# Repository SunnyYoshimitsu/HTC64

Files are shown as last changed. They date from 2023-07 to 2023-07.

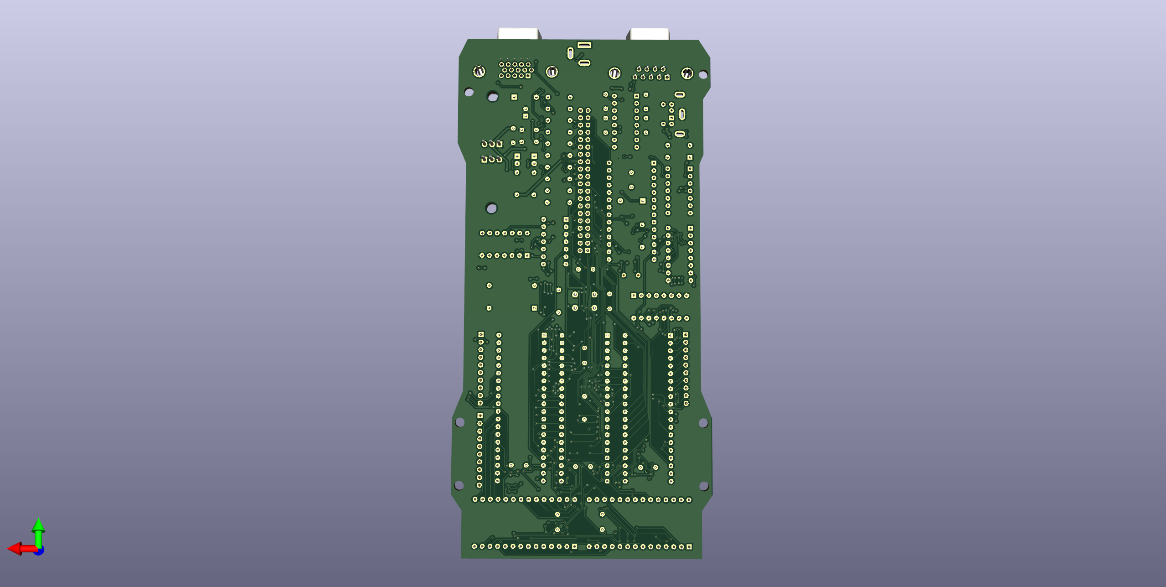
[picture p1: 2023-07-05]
Picture Y!6502/Back Visual.png

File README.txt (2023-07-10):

# Y!6502
Think Ben Eater's 6502 but modified....a modified BE6592...the Y!6502....

I modified this computer to have 2 VIA chips instead of just one since I think having more GPIO will allow it to be used as a more conventional microcontroller. Also I changed the memory layout and add a larger RAM. So the memory layout ended up being inverted to Ben's, 32k of RAM and 16k of ROM. There's an expansion slot in the middle designed to take a stock Ben Eater's GPU with its !DMA config or any other peripherals you want. The expansion slot is mapped to A000 - BFFF. 

Note there's a VGA output and associtated resistors, however there are no GPU to drive it. This is for the expansion slot. I am planning a "modified" BE6502 GPU that uses a dual port RAM so that the CPU can run at 100% capacity. Now this computer is basically everything that the BE6502 is except for the GPU but ofcourse you don't have to populate everything. 

I'm porting Wozmon to this modifed BE6502 since the UART is in a different place and it does support a keyboard. I will update this repo as soon as I'm done with it. 

If you have any question or ideas please don't hesitate to hit me up! I am an active user in the r/beneater subreddit. 
Profile: https://www.reddit.com/user/YoshimitsuSunny

Memory Layout: 
	Note: each section is 8k in size
0000 - 1FFF: RAM
2000 - 3FFF: RAM 
4000 - 5FFF: RAM 
6000 - 7FFF: RAM
8000 - 9FFF: DDRAM 
A000 - BFFF: Peripheral
A200 - UART
A400 - A40F: I/O Timer 1
  Reg A: GPIO
  Reg B: P/S 2
A800 - A80F: I/O Timer 2
  Reg A: GPIO
  Reg B: GPIO
C000 - DFFF: ROM (lower address) 
E000 - FFFF: ROM (higher address)

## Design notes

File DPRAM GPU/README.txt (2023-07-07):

The PCB version is incomplete!!!!!! Don't use it. I'll fix it at a later date. However, the schematic should be correct. Have fun!

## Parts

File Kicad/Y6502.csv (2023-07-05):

# | Reference | Qty | Value | Footprint | DNP
1 | A6522 | 1 | I/O Timer 1 | Package_DIP:DIP-40_W15.24mm_Socket
2 | B6522 | 1 | I/O Timer 2 | Package_DIP:DIP-40_W15.24mm_Socket
3 | C1 | 1 | .1uF | Capacitor_THT:C_Disc_D6.0mm_W2.5mm_P5.00mm
4 | C2, C4, C5, C6, C7, C8, C9, C10, C12, C13, C14, C15, C16, C17 | 14 | 1uF | Capacitor_THT:C_Disc_D6.0mm_W2.5mm_P5.00mm
5 | C3 | 1 | 47uF | Capacitor_THT:CP_Radial_D5.0mm_P2.50mm
6 | C11 | 1 | 20uF | Capacitor_THT:C_Disc_D6.0mm_W2.5mm_P5.00mm
7 | D1, D5 | 2 | 1N4007 | Diode_THT:D_A-405_P7.62mm_Horizontal
8 | D2, D3 | 2 | LED | LED_THT:LED_D3.0mm
9 | D4 | 1 | 1N914 | Diode_THT:D_DO-35_SOD27_P7.62mm_Horizontal
10 | J1 | 1 | Barrel_Jack_Power | Connector_BarrelJack:BarrelJack_GCT_DCJ200-10-A_Horizontal
11 | J2 | 1 | P/S 2 Breakout | Custom_Footprints:Connector_Mini-DIN_Female_6Pin_2rows
12 | J3 | 1 | R232 Plug | Connector_Dsub:DSUB-9_Female_Horizontal_P2.77x2.84mm_EdgePinOffset9.90mm_Housed_MountingHolesOffset11.32mm
13 | R1, R2 | 2 | 1k | Resistor_THT:R_Axial_DIN0207_L6.3mm_D2.5mm_P7.62mm_Horizontal
14 | R3, R4 | 2 | 22K | Resistor_THT:R_Axial_DIN0207_L6.3mm_D2.5mm_P7.62mm_Horizontal
15 | R5 | 1 | 33k | Resistor_THT:R_Axial_DIN0207_L6.3mm_D2.5mm_P7.62mm_Horizontal
16 | R6, R7, R8 | 3 | 1.5k | Resistor_THT:R_Axial_DIN0207_L6.3mm_D2.5mm_P7.62mm_Horizontal
17 | R9, R10, R11 | 3 | 680 | Resistor_THT:R_Axial_DIN0207_L6.3mm_D2.5mm_P7.62mm_Horizontal
18 | R12, R13 | 2 | 220 | Resistor_THT:R_Axial_DIN0207_L6.3mm_D2.5mm_P7.62mm_Horizontal
19 | R14, R15 | 2 | 100 | Resistor_THT:R_Axial_DIN0207_L6.3mm_D2.5mm_P7.62mm_Horizontal
20 | ROM1 | 1 | 27C128 ROM | Package_DIP:DIP-28_W15.24mm_Socket
21 | Rw9 | 1 | 1M | Resistor_THT:R_Axial_DIN0207_L6.3mm_D2.5mm_P7.62mm_Horizontal
22 | SW1 | 1 | SW_Push | Button_Switch_THT:SW_PUSH_6mm
23 | U1, U7, U8 | 3 | ~ | Connector_PinSocket_2.54mm:PinSocket_1x10_P2.54mm_Vertical
24 | U2, U4 | 2 | LM1117DT-5.0 | Package_TO_SOT_THT:TO-220-3_Horizontal_TabDown
25 | U3 | 1 | 6502 CPU | Package_DIP:DIP-40_W15.24mm_Socket
26 | U5 | 1 | 74LS00 | Package_DIP:DIP-14_W7.62mm
27 | U6 | 1 | 74LS32 | Package_DIP:DIP-14_W7.62mm
28 | U12 | 1 | 74LS14 | Package_DIP:DIP-14_W7.62mm
29 | U13, U14 | 2 | 74LS595 | Package_DIP:DIP-16_W7.62mm
30 | U15 | 1 | 6551 | Package_DIP:DIP-28_W15.24mm_Socket
31 | U16 | 1 | MAX232 | Package_DIP:DIP-16_W7.62mm
32 | URAM1 | 1 | 62256 RAM | Package_DIP:DIP-28_W15.24mm_Socket
33 | VGA1 | 1 | VGA Output | Connector_Dsub:DSUB-15-HD_Female_Horizontal_P2.29x1.98mm_EdgePinOffset8.35mm_Housed_MountingHolesOffset10.89mm
34 | X2 | 1 | 1 MHz Osc | Oscillator:Oscillator_DIP-14
35 | Y1 | 1 | 1.8432 Mhz | Crystal:Crystal_HC18-U_Vertical
36 | ~1 | 1 | ~ | Connector_PinSocket_2.54mm:PinSocket_2x20_P2.54mm_Vertical

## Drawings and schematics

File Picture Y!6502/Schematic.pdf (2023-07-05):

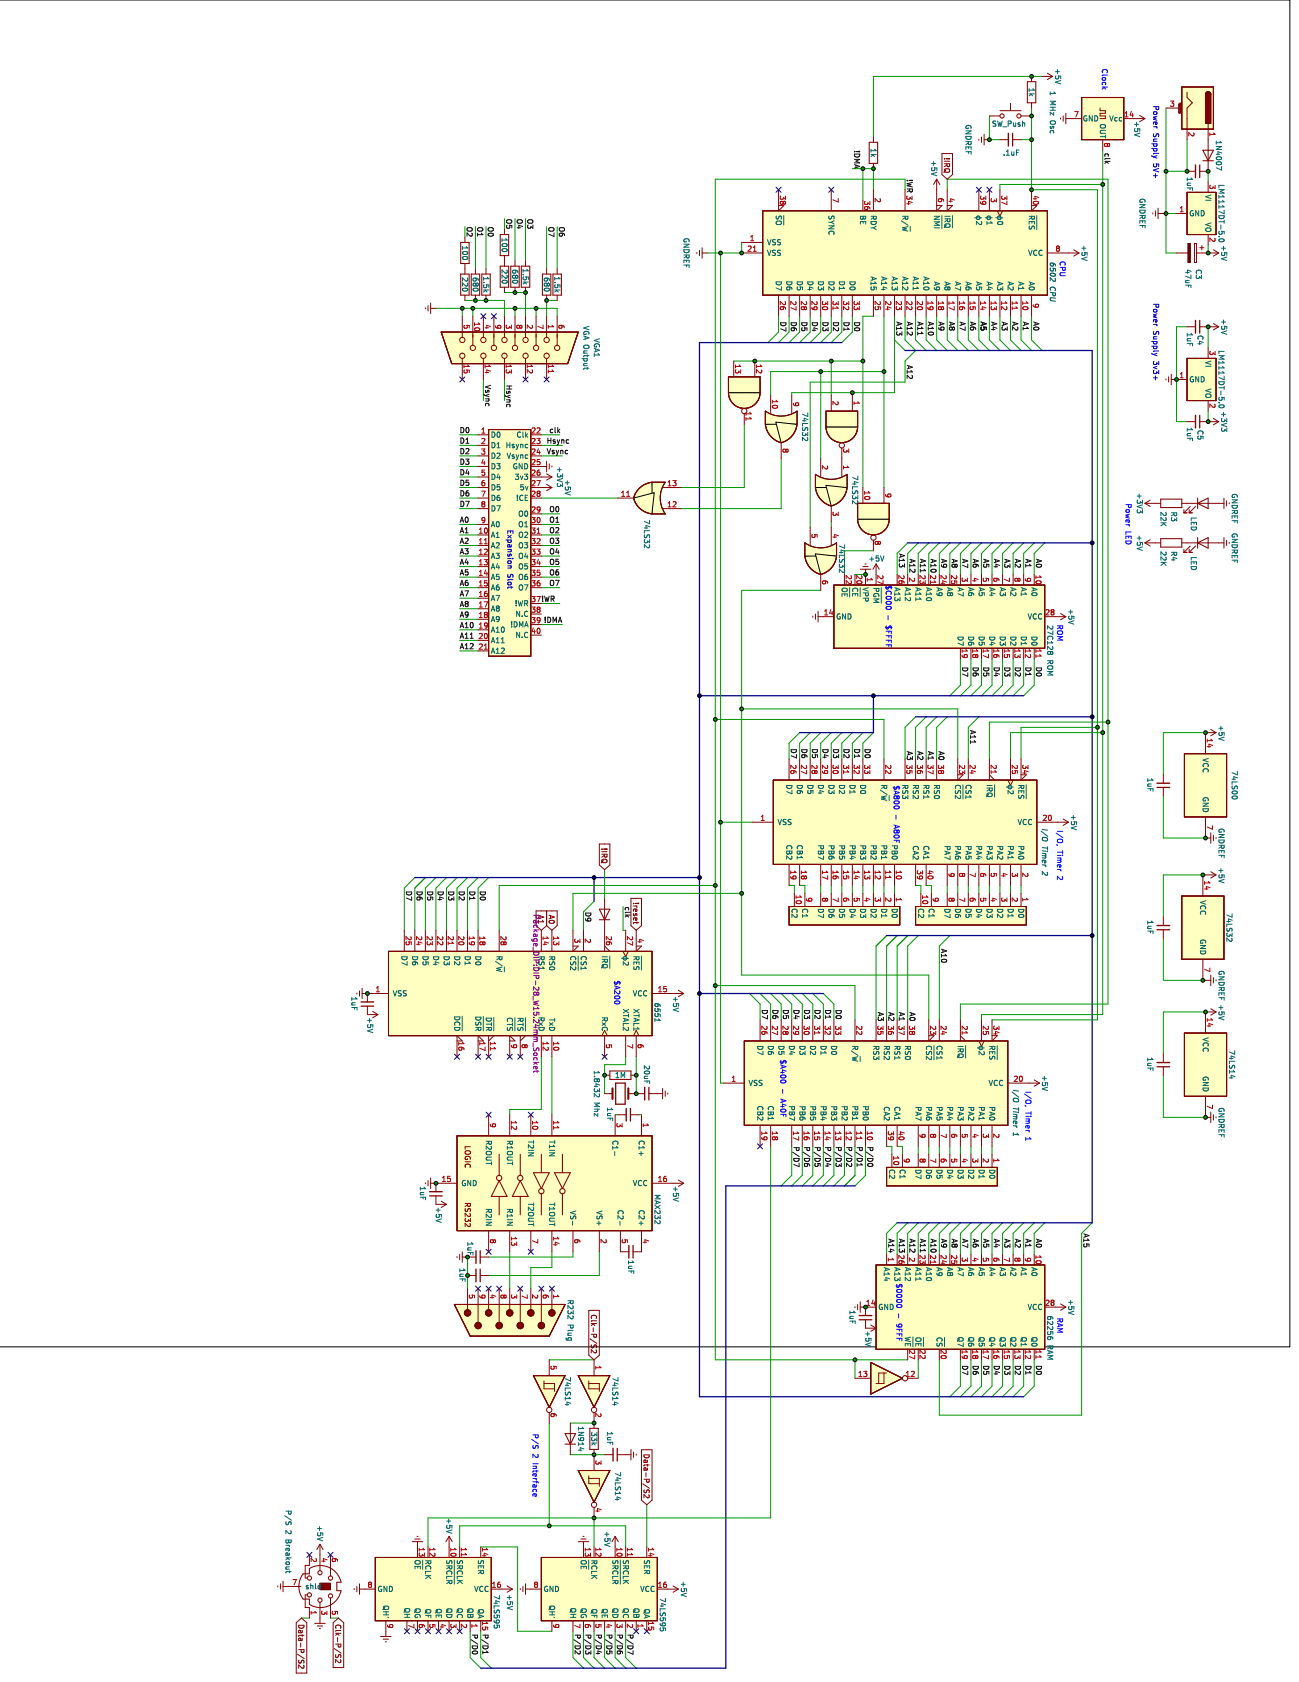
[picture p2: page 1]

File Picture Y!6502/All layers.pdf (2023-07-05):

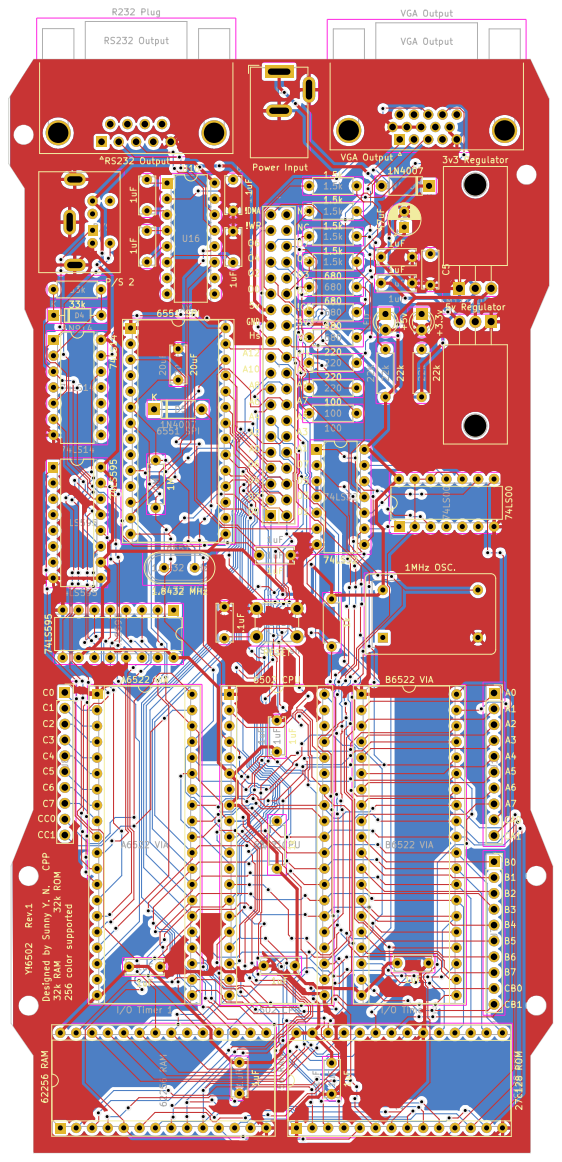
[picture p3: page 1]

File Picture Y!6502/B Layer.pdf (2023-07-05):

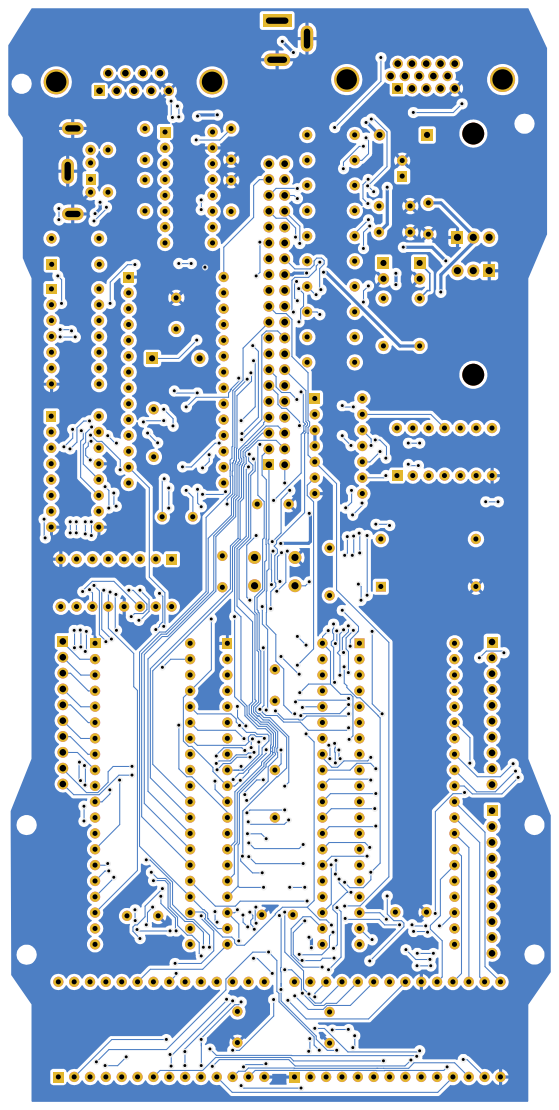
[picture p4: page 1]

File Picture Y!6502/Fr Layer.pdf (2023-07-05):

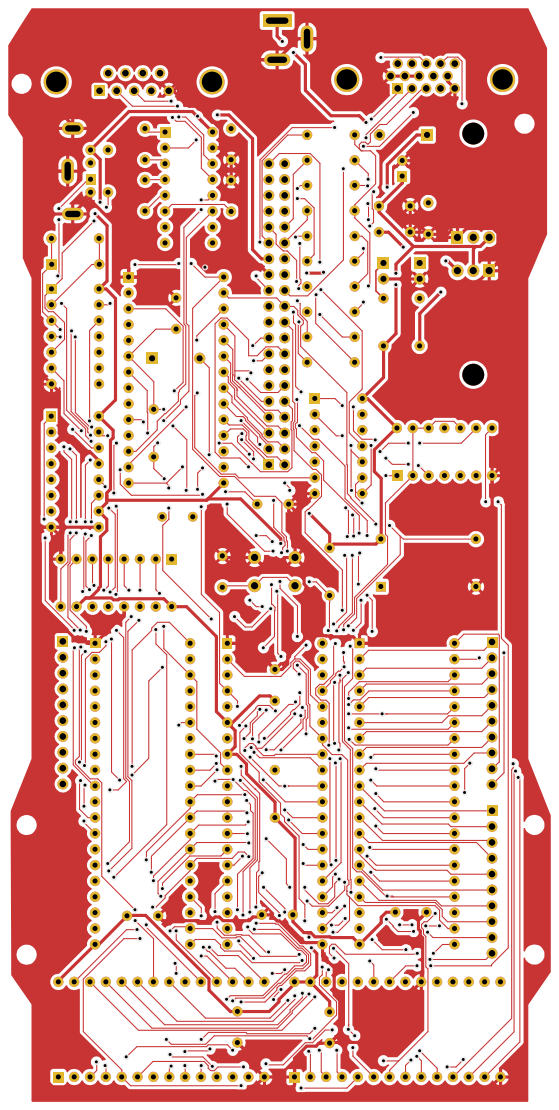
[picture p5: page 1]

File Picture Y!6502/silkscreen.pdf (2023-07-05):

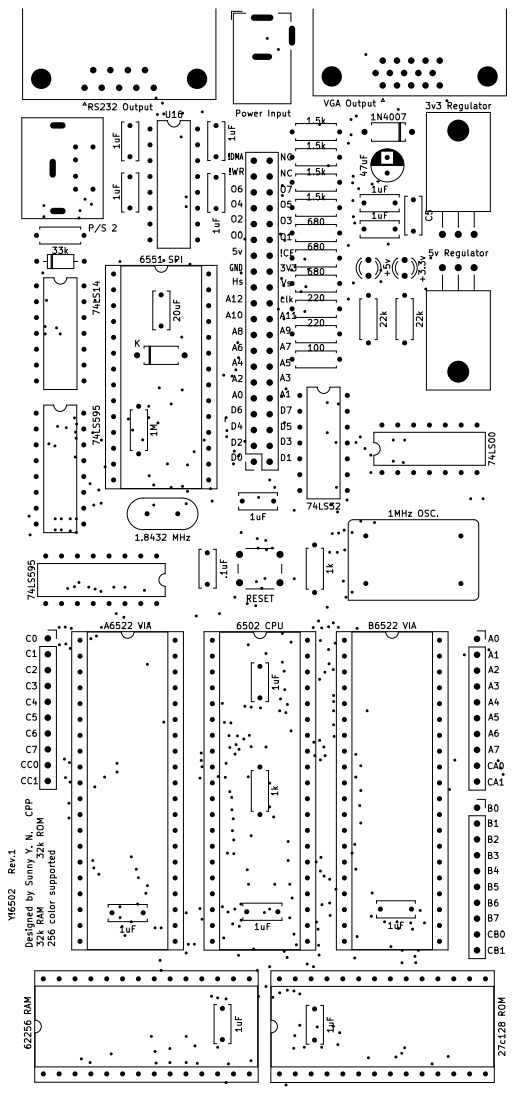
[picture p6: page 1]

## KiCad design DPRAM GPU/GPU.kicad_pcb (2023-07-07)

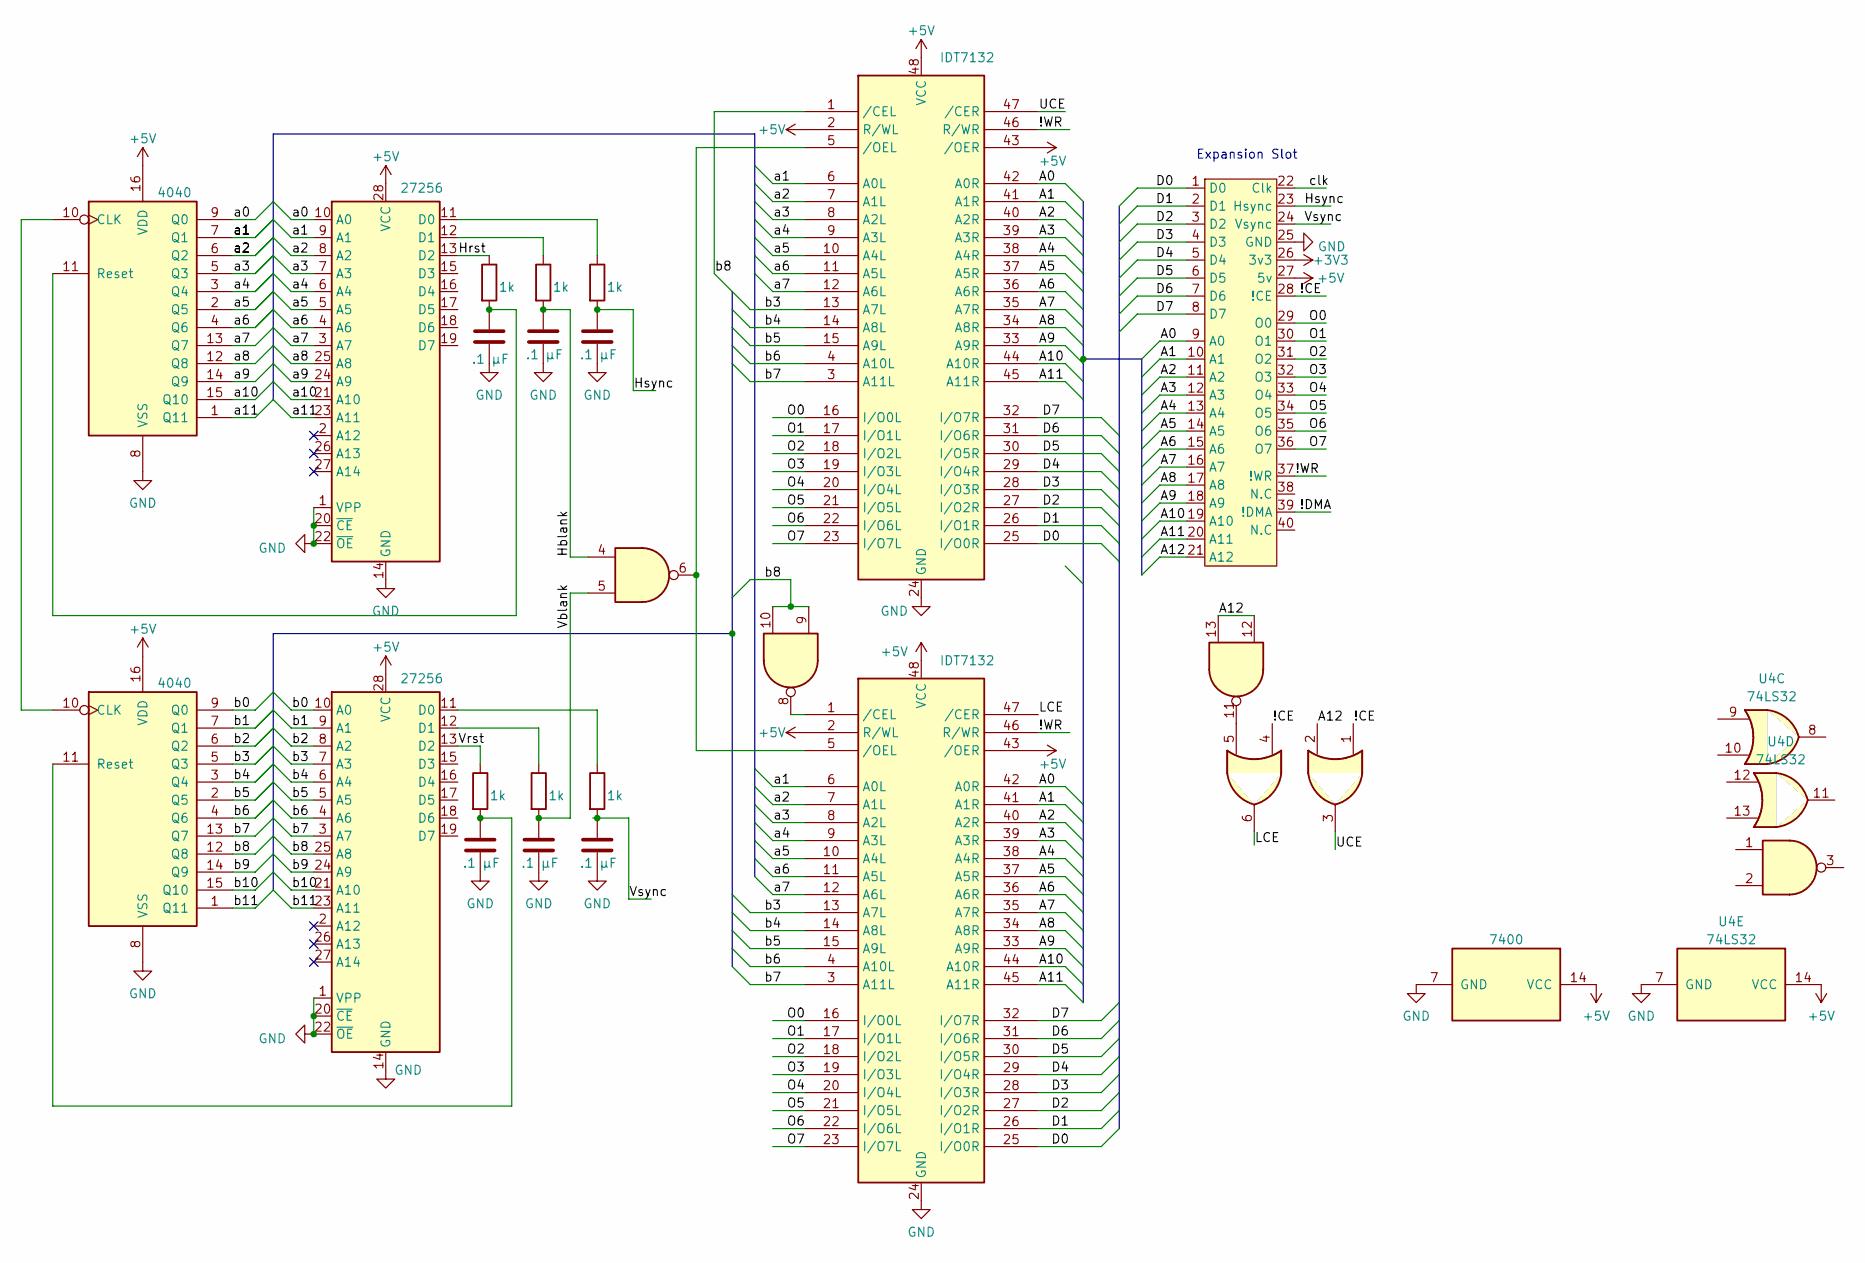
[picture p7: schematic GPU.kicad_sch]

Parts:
C1, C2, C3, C4, C5, C6: .1 μF; C_Disc_D3.4mm_W2.1mm_P2.50mm
R1, R2, R3, R4, R5, R6: 1k; R_Axial_DIN0207_L6.3mm_D2.5mm_P7.62mm_Horizontal
U1, U3: 4040; DIP-16_W7.62mm_Socket
U2, U8: 27256; DIP-28_W15.24mm_Socket
U4: 74LS32; DIP-14_W7.62mm
U5, U6: IDT7132; DIP-48_W15.24mm_Socket
U7: 7400; DIP-14_W7.62mm_Socket
~1: Y!6502 exp

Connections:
+5V: U1.16 (VDD), U2.28 (VCC), U3.16 (VDD), U4.14 (VCC), U5.2 (R/WL), U5.43 (/OER), U5.48 (VCC), U6.2 (R/WL), U6.43 (/OER), U6.48 (VCC), U7.14 (VCC), U8.28 (VCC), ~1.27 (5v)
/!CE: U4.1, U4.4, ~1.28 (!CE)
/!WR: U5.46 (R/WR), U6.46 (R/WR), ~1.37 (!WR)
/A0: U5.42 (A0R), U6.42 (A0R), ~1.9 (A0)
/A1: U5.41 (A1R), U6.41 (A1R), ~1.10 (A1)
/A2: U5.40 (A2R), U6.40 (A2R), ~1.11 (A2)
/A3: U5.39 (A3R), U6.39 (A3R), ~1.12 (A3)
/A4: U5.38 (A4R), U6.38 (A4R), ~1.13 (A4)
/A5: U5.37 (A5R), U6.37 (A5R), ~1.14 (A5)
/A6: U5.36 (A6R), U6.36 (A6R), ~1.15 (A6)
/A7: U5.35 (A7R), U6.35 (A7R), ~1.16 (A7)
/A8: U5.34 (A8R), U6.34 (A8R), ~1.17 (A8)
/A9: U5.33 (A9R), U6.33 (A9R), ~1.18 (A9)
/A10: U5.44 (A10R), U6.44 (A10R), ~1.19 (A10)
/A11: U5.45 (A11R), U6.45 (A11R), ~1.20 (A11)
/A12: U4.2, U7.12, U7.13, ~1.21 (A12)
/D0: U5.25 (I/O0R), U6.25 (I/O0R), ~1.1 (D0)
/D1: U5.26 (I/O1R), U6.26 (I/O1R), ~1.2 (D1)
/D2: U5.27 (I/O2R), U6.27 (I/O2R), ~1.3 (D2)
/D3: U5.28 (I/O3R), U6.28 (I/O3R), ~1.4 (D3)
/D4: U5.29 (I/O4R), U6.29 (I/O4R), ~1.5 (D4)
/D5: U5.30 (I/O5R), U6.30 (I/O5R), ~1.6 (D5)
/D6: U5.31 (I/O6R), U6.31 (I/O6R), ~1.7 (D6)
/D7: U5.32 (I/O7R), U6.32 (I/O7R), ~1.8 (D7)
/Hblank: C2.1, R2.2, U7.4
/Hrst: R1.1, U8.13 (D2)
/Hsync: C3.1, R3.2, ~1.23 (Hsync)
/LCE: U4.6, U6.47 (/CER)
/O0: U5.16 (I/O0L), U6.16 (I/O0L), ~1.29 (O0)
/O1: U5.17 (I/O1L), U6.17 (I/O1L), ~1.30 (O1)
/O2: U5.18 (I/O2L), U6.18 (I/O2L), ~1.31 (O2)
/O3: U5.19 (I/O3L), U6.19 (I/O3L), ~1.32 (O3)
/O4: U5.20 (I/O4L), U6.20 (I/O4L), ~1.33 (O4)
/O5: U5.21 (I/O5L), U6.21 (I/O5L), ~1.34 (O5)
/O6: U5.22 (I/O6L), U6.22 (I/O6L), ~1.35 (O6)
/O7: U5.23 (I/O7L), U6.23 (I/O7L), ~1.36 (O7)
/UCE: U4.3, U5.47 (/CER)
/Vblank: C5.1, R5.2, U7.5
/Vrst: R4.1, U2.13 (D2)
/Vsync: C6.1, R6.2, ~1.24 (Vsync)
/a0: U1.9 (Q0), U8.10 (A0)
/a1: U1.7 (Q1), U5.6 (A0L), U6.6 (A0L), U8.9 (A1)
/a2: U1.6 (Q2), U5.7 (A1L), U6.7 (A1L), U8.8 (A2)
/a3: U1.5 (Q3), U5.8 (A2L), U6.8 (A2L), U8.7 (A3)
/a4: U1.3 (Q4), U5.9 (A3L), U6.9 (A3L), U8.6 (A4)
/a5: U1.2 (Q5), U5.10 (A4L), U6.10 (A4L), U8.5 (A5)
/a6: U1.4 (Q6), U5.11 (A5L), U6.11 (A5L), U8.4 (A6)
/a7: U1.13 (Q7), U5.12 (A6L), U6.12 (A6L), U8.3 (A7)
/a8: U1.12 (Q8), U8.25 (A8)
/a9: U1.14 (Q9), U8.24 (A9)
/a10: U1.15 (Q10), U8.21 (A10)
/a11: U1.1 (Q11), U8.23 (A11)
/b0: U2.10 (A0), U3.9 (Q0)
/b1: U2.9 (A1), U3.7 (Q1)
/b2: U2.8 (A2), U3.6 (Q2)
/b3: U2.7 (A3), U3.5 (Q3), U5.13 (A7L), U6.13 (A7L)
/b4: U2.6 (A4), U3.3 (Q4), U5.14 (A8L), U6.14 (A8L)
/b5: U2.5 (A5), U3.2 (Q5), U5.15 (A9L), U6.15 (A9L)
/b6: U2.4 (A6), U3.4 (Q6), U5.4 (A10L), U6.4 (A10L)
/b7: U2.3 (A7), U3.13 (Q7), U5.3 (A11L), U6.3 (A11L)
/b8: U2.25 (A8), U3.12 (Q8), U5.1 (/CEL), U7.9, U7.10
/b9: U2.24 (A9), U3.14 (Q9)
/b10: U2.21 (A10), U3.15 (Q10)
/b11: U2.23 (A11), U3.1 (Q11)
GND: C1.2, C2.2, C3.2, C4.2, C5.2, C6.2, U1.8 (VSS), U2.1 (VPP), U2.14 (GND), U2.20 (~CE), U2.22 (~OE), U3.8 (VSS), U4.7 (GND), U5.24 (GND), U6.24 (GND), U7.7 (GND), U8.1 (VPP), U8.14 (GND), U8.20 (~CE), U8.22 (~OE), ~1.25 (GND)
unnamed: U1.10 (CLK), U3.10 (CLK)
unnamed: C1.1, R1.2, U1.11 (Reset)
unnamed: R6.1, U2.11 (D0)
unnamed: R5.1, U2.12 (D1)
unnamed: C4.1, R4.2, U3.11 (Reset)
unnamed: U4.5, U7.11
unnamed: U5.5 (/OEL), U6.5 (/OEL), U7.6
unnamed: U6.1 (/CEL), U7.8
unnamed: R3.1, U8.11 (D0)
unnamed: R2.1, U8.12 (D1)

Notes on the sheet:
Expansion Slot

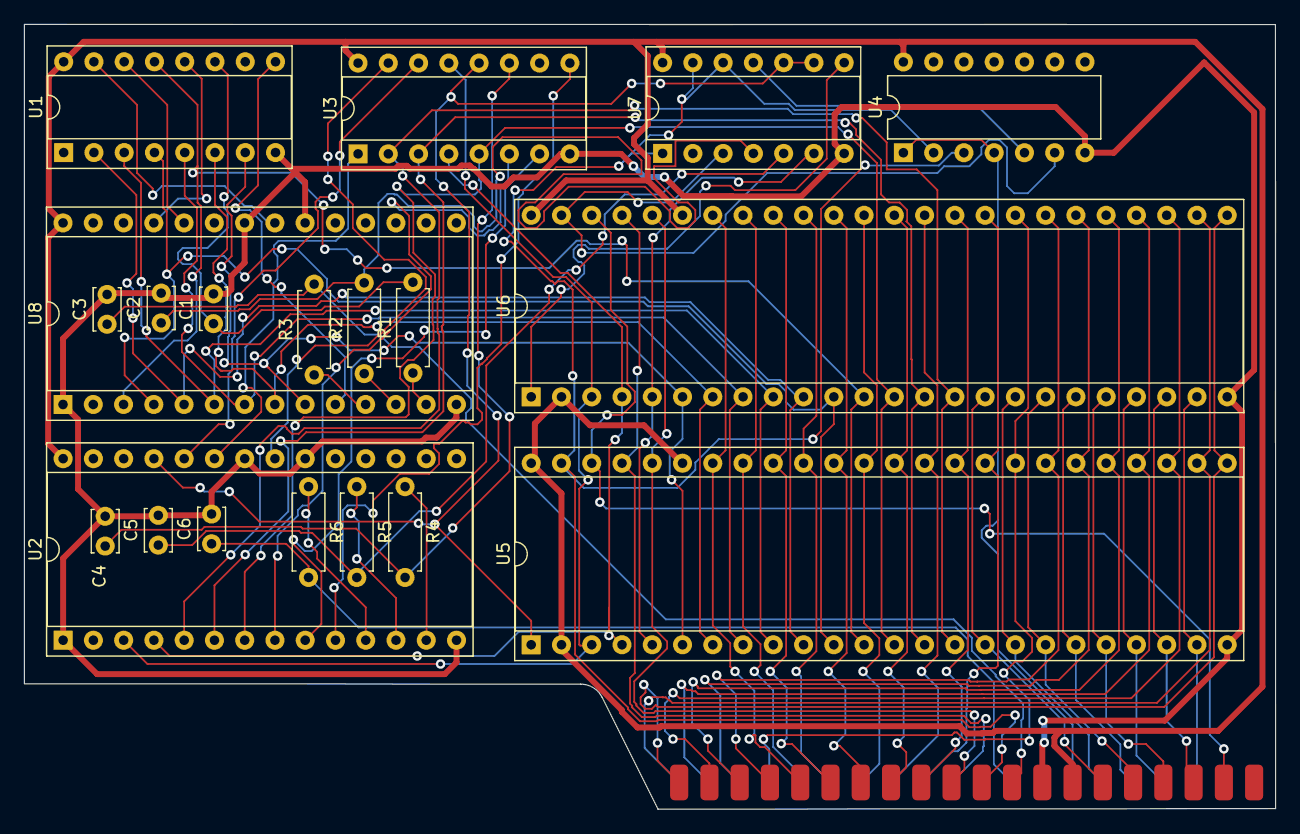
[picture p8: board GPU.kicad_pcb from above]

Board: 2 copper layers, 105.0 x 65.9 mm, 20 parts (0 on the bottom side), 75 nets.

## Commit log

2023-07-05 second commit
    [Y6502-B_Cu.gbr, Y6502-B_Mask.gbr, Y6502-B_Paste.gbr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]
2023-07-07 fourth commit
    [GPU.kicad_pcb, GPU.kicad_sch]

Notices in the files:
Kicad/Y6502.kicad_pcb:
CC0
